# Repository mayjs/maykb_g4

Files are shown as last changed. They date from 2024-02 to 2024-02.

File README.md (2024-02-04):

# maykb G4

This is my fourth custom split keyboard, this time using an ANSI layout.

## Caveats / Known Issues

In its current form, the level shifter for the WS2812b LEDs does NOT work.
With most clones, you can just remove the Mosfet and the two resistors next to it and bridge the microcontroller LED data input directly to the LED data input.
Some LEDs might not properly recognize the 3.3V signal though, so you might see some glitches due to this.

Otherwise, the keyboard works without any issues.

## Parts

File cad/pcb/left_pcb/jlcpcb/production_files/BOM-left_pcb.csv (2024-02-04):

Comment | Designator | Footprint | LCSC
1k | R1,R2,R7 | R_0402_1005Metric | C11702
W25Q128JVS | U1 | SOIC-8_5.23x5.23mm_P1.27mm | C131025
100nF | C1,C10,C11,C12,C13,C14,C15,C18,C19,C20,C5,C6,C9 | C_0402_1005Metric | C1525
10uF | C7 | C_0402_1005Metric | C15525
22pF | C2,C3 | C_0402_1005Metric | C1555
USB_C_Receptacle_USB2.0 | J1 | USB_C_Receptacle_HRO_TYPE-C-31-M-12 | C165948
RP2040 | U3 | RP2040-QFN-56 | C2040
D | D1,D10,D11,D12,D13,D14,D15,D16,D17,D18,D19,D2,D20,D21,D22,D23,D24,D25,D26,D27,D28,D29,D3,D30,D31,D32,D4,D5,D6,D7,D8,D9 | D_SOD-323F | C2128
27R | R5,R6 | R_0603_1608Metric | C25190
5k1 | R3,R4 | R_0402_1005Metric | C25905
USBLC6-2SC6 | U2 | SOT-23-6 | C2827654
1uF | C16,C17,C4,C8 | C_0402_1005Metric | C52923
XC6206PxxxMR-Regulator_Linear | U4 | SOT-23 | C5446
ConnLeft | J3,J4 | PJ-342B | C668606
500mA | F1 | Fuse_1206_3216Metric | C70076
12MHz | Y1 | Crystal_SMD_3225-4Pin_3.2x2.5mm | C9002
10k | R8 | R_0603_1608Metric_Pad0.98x0.95mm_HandSolder
BSS138 | Q1 | SOT-23
10k | R9 | R_0603_1608Metric_Pad0.98x0.95mm_HandSolder

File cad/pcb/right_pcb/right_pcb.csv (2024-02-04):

Id | Designator | Footprint | Quantity | Designation | Supplier and ref
1 | LED3,LED1,LED2 | LED_WS2812B_PLCC4_5.0x5.0mm_P3.2mm | 3 | WS2812B
2 | SW49,SW48,SW55,SW70,SW75,SW54,SW39,SW57,SW74,SW76,SW47,SW62,SW66,SW33,SW50,SW35,SW45,SW73,SW59,SW42,SW34,SW63,SW58,SW61,SW41,SW43,SW51,SW64,SW38,SW60,SW44,SW36,SW40,SW53,SW52,SW46,SW72,SW71,SW56 | SW_Cherry_MX_1.00u_PCB | 39 | SW_Push_45deg
3 | SW69 | SW_Cherry_MX_2.25u_PCB | 1 | SW_Push_45deg
4 | SW67,SW37 | SW_Cherry_MX_2.00u_PCB | 2 | SW_Push_45deg
5 | SW68 | SW_Cherry_MX_1.50u_PCB | 1 | SW_Push_45deg
6 | SW65 | SW_Cherry_MX_1.75u_PCB | 1 | SW_Push_45deg
7 | C17,C8,C16,C4 | C_0402_1005Metric | 4 | 1uF
8 | C6,C1,C9,C14,C10,C13,C15,C18,C20,C19,C5,C12,C11 | C_0402_1005Metric | 13 | 100nF
9 | D46,D56,D53,D38,D43,D52,D36,D67,D39,D66,D47,D68,D75,D41,D48,D54,D35,D34,D65,D40,D50,D59,D37,D49,D58,D70,D42,D73,D51,D60,D44,D71,D55,D45,D72,D33,D61,D62,D63,D57,D64,D76,D74,D69 | D_SOD-323F | 44 | 1N4148
10 | U3 | RP2040-QFN-56 | 1 | RP2040
11 | R9,R8 | R_0603_1608Metric_Pad0.98x0.95mm_HandSolder | 2 | 10k
12 | C7 | C_0402_1005Metric | 1 | 10uF
13 | U1 | SOIC-8_5.23x5.23mm_P1.27mm | 1 | W25Q128JVS
14 | U2 | SOT-23-6 | 1 | USBLC6-2SC6
15 | C3,C2 | C_0402_1005Metric | 2 | 22pF
16 | R6,R5 | R_0603_1608Metric | 2 | 27R
17 | J4 | PJ-342B | 1 | ConnRight
18 | F1 | Fuse_1206_3216Metric | 1 | 500mA
19 | Y1 | Crystal_SMD_3225-4Pin_3.2x2.5mm | 1 | 12MHz
20 | Q1 | SOT-23 | 1 | BSS138
21 | R2,R1,R7 | R_0402_1005Metric | 3 | 1k
22 | R3,R4 | R_0402_1005Metric | 2 | 5k1
23 | J3 | PJ-342B | 1 | ConnLeft
24 | SW_RESET1 | SW_SPST_TL3342 | 1 | SW_Push
25 | J1 | USB_C_Receptacle_HRO_TYPE-C-31-M-12 | 1 | USB_C_Receptacle_USB2.0
26 | U4 | SOT-23 | 1 | XC6206PxxxMR-Regulator_Linear

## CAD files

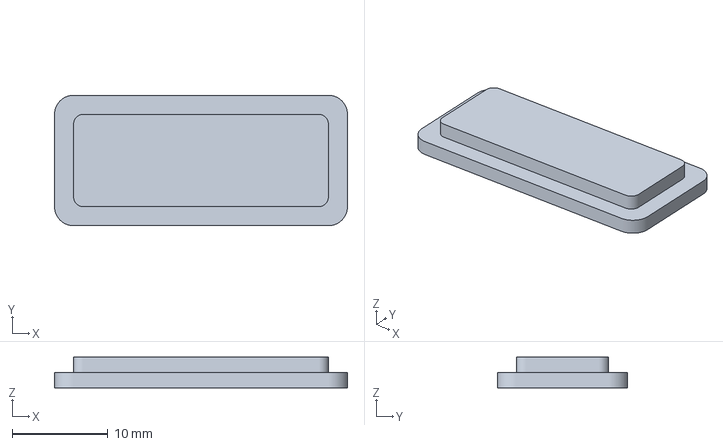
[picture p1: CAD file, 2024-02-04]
cad/case/led_cover.amf
30.7 x 13.7 x 3.20 mm

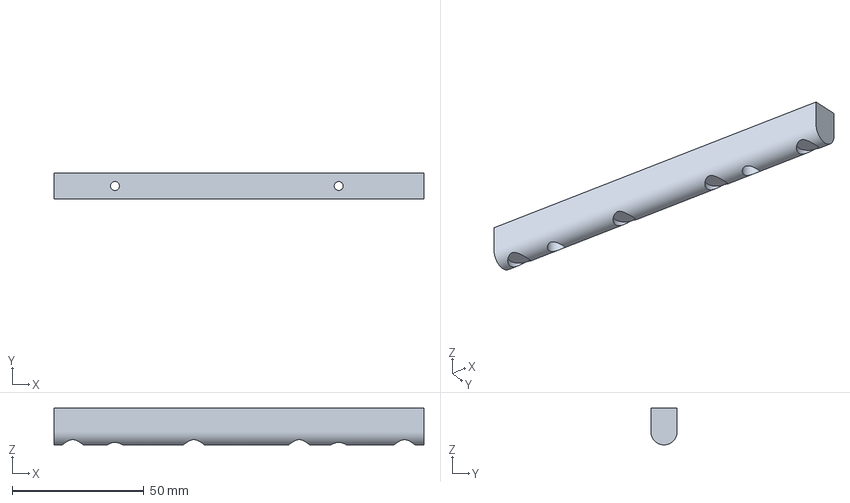
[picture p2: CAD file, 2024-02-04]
cad/case/left/left_bar.amf
140.5 x 10.0 x 14.0 mm

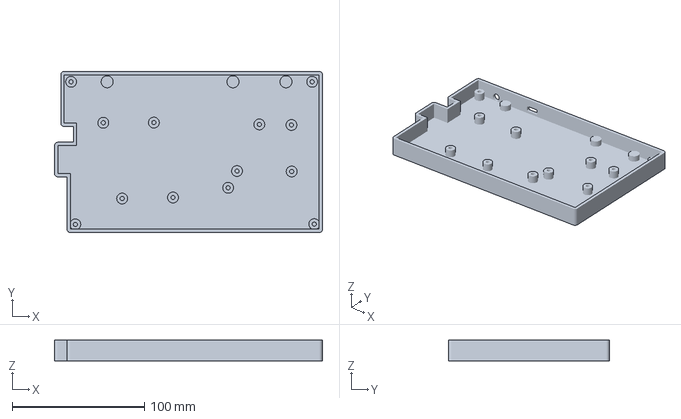
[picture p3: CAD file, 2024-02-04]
cad/case/right/right_case.amf
202.4 x 121.7 x 15.6 mm

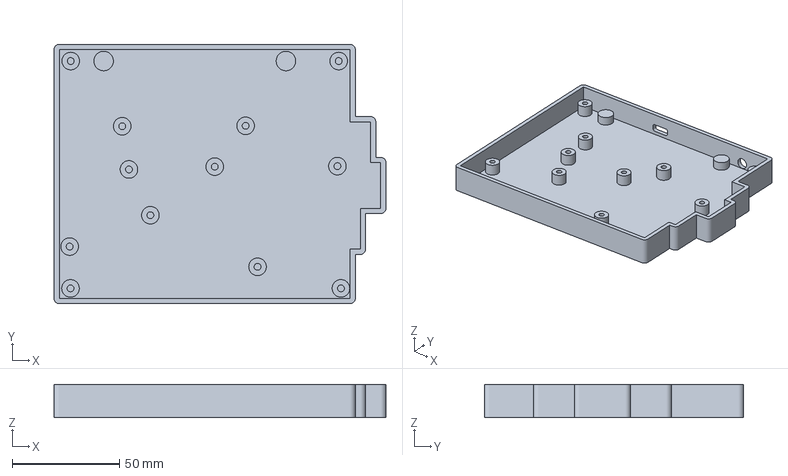
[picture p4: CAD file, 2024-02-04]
cad/case/left/left_case.amf
154.8 x 121.0 x 15.6 mm

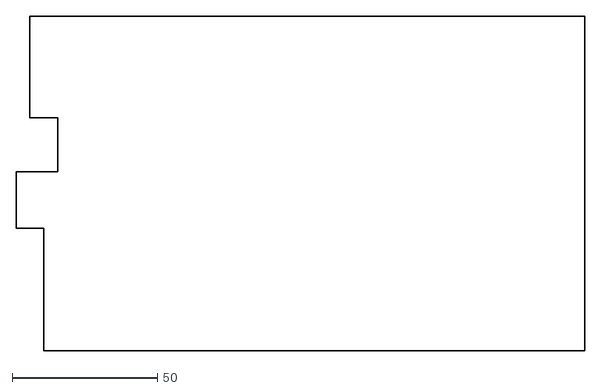
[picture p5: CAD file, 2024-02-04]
cad/case/right/right_pcb-Edge_Cuts.dxf
195.8 x 115.1

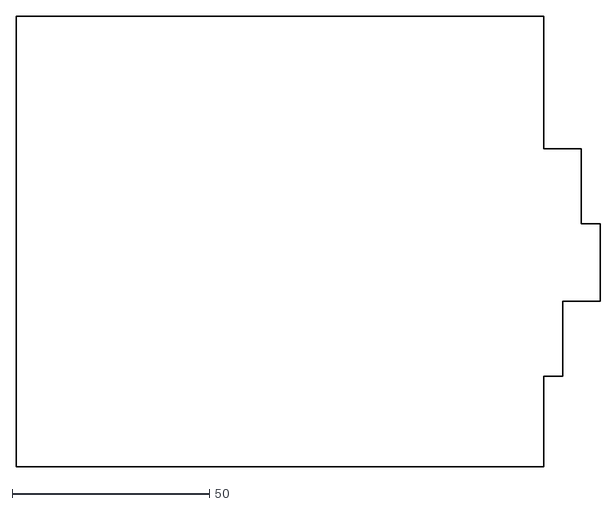
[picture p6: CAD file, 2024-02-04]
cad/case/left/left_pcb-Edge_Cuts.dxf
148.2 x 114.4

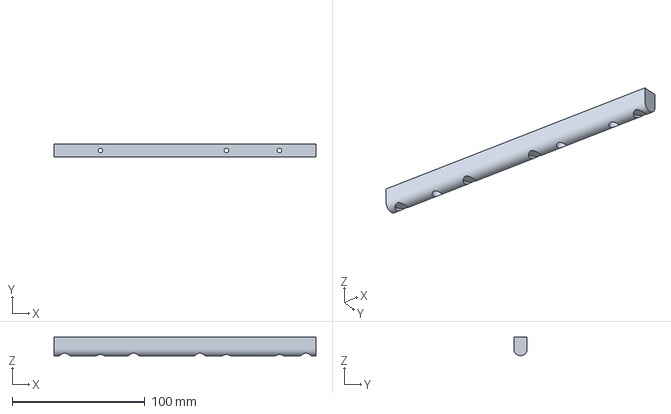
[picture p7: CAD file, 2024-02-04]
cad/case/right/right_bar.amf
197.7 x 10.0 x 14.0 mm

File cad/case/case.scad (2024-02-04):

// The case side to build
case_side = "left"; // [left, right]

// The part of the case to build
case_part = "case"; // [case, bar]

// The general amount of wiggle-room
play = .2;

// The amount of wiggle-room around the pcb and plate in the case
case_play = .8;

// The thickness of the outer case wall
wall_thickness = 2.5; // 0.1

// The drill diameter for the screw inserts
screw_insert_dia = 3.2;

// The length of the hole for the screw inserts
screw_insert_hole_length = 6.5;

// The total height of the plate-pcb sandwich
plate_pcb_height = 6.6;

// The diameter of the audio plug
audio_plug_dia = 6.2;

// The diameter of the mount holes for the angle bar
screw_insert_angle_bar_dia = 4.1;

// The length of the hole to mount the angle bar
screw_insert_angle_bar_hole_length = 5;

// The width of the angle bar
angle_bar_width = 10;

// The maximum allowed width for the bar (this should be larger than the keyboard / case)
max_bar_length = 300;

// the height of the angle bar (this must be at least angle_bar_width / 2)
angle_bar_height = 14;

// The diameter of the rubber bumpers
bumper_dia = 8;

$fn = 100;

is_left = case_side == "left" ? true : false;

edge_file = is_left ? "left/left_pcb-Edge_Cuts.dxf" : "right/right_pcb-Edge_Cuts.dxf";

use <left/coordinates.scad>
use <right/coordinates.scad>

mount_positions = is_left ? kb_mount_centers_left() : kb_mount_centers_right();
jack_positions = is_left ? [max(audio_jack_x_left())] : [min(audio_jack_x_right())];
usb_c_position = is_left ? usb_c_x_left() : usb_c_x_right();
angle_bar_mount_positions = is_left ? [50, 135] : [75, 170, 210];
bumper_mount_positions = is_left ? [34, 80, 120, 160] : [48, 100, 150, 230];

angle_bar_y_position = -min([for(pos = mount_positions) pos.y]);

usb_c_jack_bounds = [10, 4];
 
use <mayscadlib/2d/shapes.scad>
use <mayscadlib/3d/screws.scad>
use <mayscadlib/positioning.scad>

module outline() {
    offset(delta=case_play)
    import(edge_file);
}

module wall_2d() {
  difference() {
    offset(r=wall_thickness)
    outline();
    outline();
  }
}

module bare_case() {
    linear_extrude(wall_thickness) {
        wall_2d();
        outline();
    }

    linear_extrude(wall_thickness + screw_insert_hole_length + plate_pcb_height)
    wall_2d();
}

module mounting_post() {
    linear_extrude(screw_insert_hole_length)
    difference() {
        circle(r=screw_insert_dia/2 + wall_thickness);
        circle(r=screw_insert_dia/2);
    }
}

module mounts() {
    for(pos = mount_positions) {
        translate([pos.x, -pos.y, wall_thickness - .0001]) {
            mounting_post();        
        }
    }
}

module connector_cutouts() {
    // usb-c
    bounds_with_play = usb_c_jack_bounds + [2*play, 2*play];
    translate([usb_c_position.x, 0, wall_thickness + screw_insert_hole_length - bounds_with_play.y/2])
    rotate([90,0,0])
    linear_extrude(100)
    rounded_square(bounds_with_play, corner_rad=1, center=true);

    // audio jack
    for(pos = jack_positions) {
        rad = audio_plug_dia/2 + play/2;
        translate([pos, 0, wall_thickness + screw_insert_hole_length - rad])
        rotate([90,0,0])
        cylinder(r=rad, 100);
    }
}

module case_with_angle_bar_mounts() {
    difference() {
        union() {
            bare_case();
            for(mx = angle_bar_mount_positions) {
                translate([mx, angle_bar_y_position, wall_thickness - .0001])
                cylinder(r=screw_insert_angle_bar_dia/2 + wall_thickness, h=screw_insert_angle_bar_hole_length);
            }
        }
        for(mx = angle_bar_mount_positions) {
            translate([mx, angle_bar_y_position, -.0001])
            cylinder(r=screw_insert_angle_bar_dia/2, h=screw_insert_angle_bar_hole_length);
        }
    }
}

module full_case() {
    difference() {
        case_with_angle_bar_mounts();
        connector_cutouts();
    }
    mounts();
}

module bar() {
    screw = m3_din912_cylinder_head(angle_bar_height * 2);

    bumper_plateau_inv_height = sqrt(pow(angle_bar_width/2, 2) - pow(bumper_dia/2, 2));
    bumper_plateau_height = angle_bar_width/2 - bumper_plateau_inv_height;

    difference() {
        intersection() {
            translate([0, angle_bar_y_position, angle_bar_width/2])
            rotate([90,0,90])
            linear_extrude(max_bar_length) {
                difference() {
                    circle(r=angle_bar_width/2); 
                    translate([-angle_bar_width,0])
                    square([angle_bar_width *2, angle_bar_width]);
                }

                translate([-angle_bar_width / 2, 0])
                square([angle_bar_width, angle_bar_height - angle_bar_width / 2]);
            }

            linear_extrude(max_bar_length + 1) {
                outline();
                wall_2d();
            }
        }

        for(mx = angle_bar_mount_positions) {
            translate([mx, angle_bar_y_position, angle_bar_height - screw_head_h(screw) - wall_thickness])
            mirror([0,0,1]) 
            make_screw(screw, head_clearance=angle_bar_width);

        }

        translate([0, angle_bar_y_position, -.0001])
        place([for (bx=bumper_mount_positions) [bx, 0]])
        cylinder(r=bumper_dia/2, h=bumper_plateau_height);
    }
}

if(case_part == "case") {
    full_case();
} else if (case_part == "bar") {
    bar(); 
}

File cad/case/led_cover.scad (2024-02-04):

use <mayscadlib/2d/shapes.scad>
use <mayscadlib/positioning.scad>

$fn = 100;

hole_dims = [26.67, 9.652];
lip = 2;
thickness = 1.6;

linear_extrude(thickness)
rounded_square(hole_dims + [lip*2, lip*2], corner_rad=2, center=true);

lift(thickness)
linear_extrude(thickness)
rounded_square(hole_dims, center=true);

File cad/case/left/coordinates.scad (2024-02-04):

function kb_footprint_centers_left() = [
    [90.1369,91.54],
    [113.9494,148.69],
    [166.3369,91.54],
    [147.2869,91.54],
    [54.4925,129.64],
    [71.0869,91.54],
    [61.5619,72.49],
    [137.7619,72.49],
    [161.5744,129.64],
    [47.2749,91.54],
    [92.5179,148.69],
    [109.1869,91.54],
    [42.5119,72.49],
    [80.6119,72.49],
    [118.7119,72.49],
    [94.8994,110.59],
    [68.7054,148.69],
    [123.4744,129.64],
    [113.9494,110.59],
    [156.8119,72.49],
    [85.3744,129.64],
    [99.6619,72.49],
    [128.2369,91.54],
    [144.98,148.69],
    [152.0494,110.59],
    [132.9994,110.59],
    [75.8494,110.59],
    [142.5244,129.64],
    [171.0994,110.59],
    [104.4244,129.64],
    [44.8929,148.69],
    [49.6559,110.59],
];

function kb_mount_centers_left() = [
    [160.65,163.6556],
    [58.65,88.05],
    [61.8,108.2],
    [121.75,153.6],
    [71.8,129.55],
    [159.5996,57.6556],
    [34.15,144.1556],
    [159.0,106.6556],
    [34.6496,57.6556],
    [34.5496,163.6556],
    [116.2,87.85],
    [101.8,106.9],
];

function audio_jack_x_left() = [
    48.0,
    146.1,
];

function usb_c_x_left() = [
    85.845968,
];

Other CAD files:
cad/case/right/coordinates.scad

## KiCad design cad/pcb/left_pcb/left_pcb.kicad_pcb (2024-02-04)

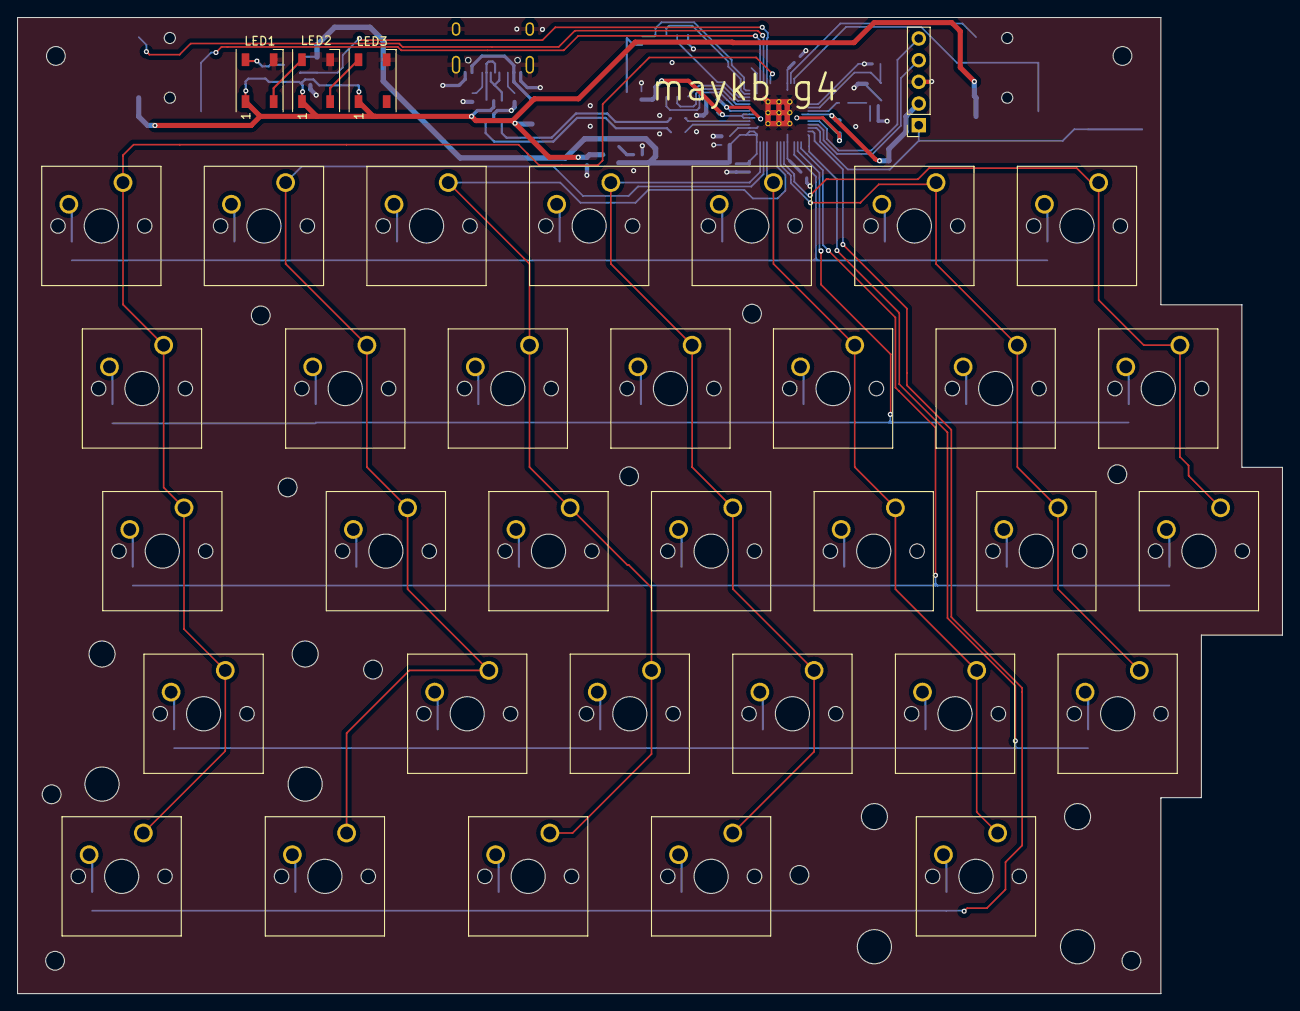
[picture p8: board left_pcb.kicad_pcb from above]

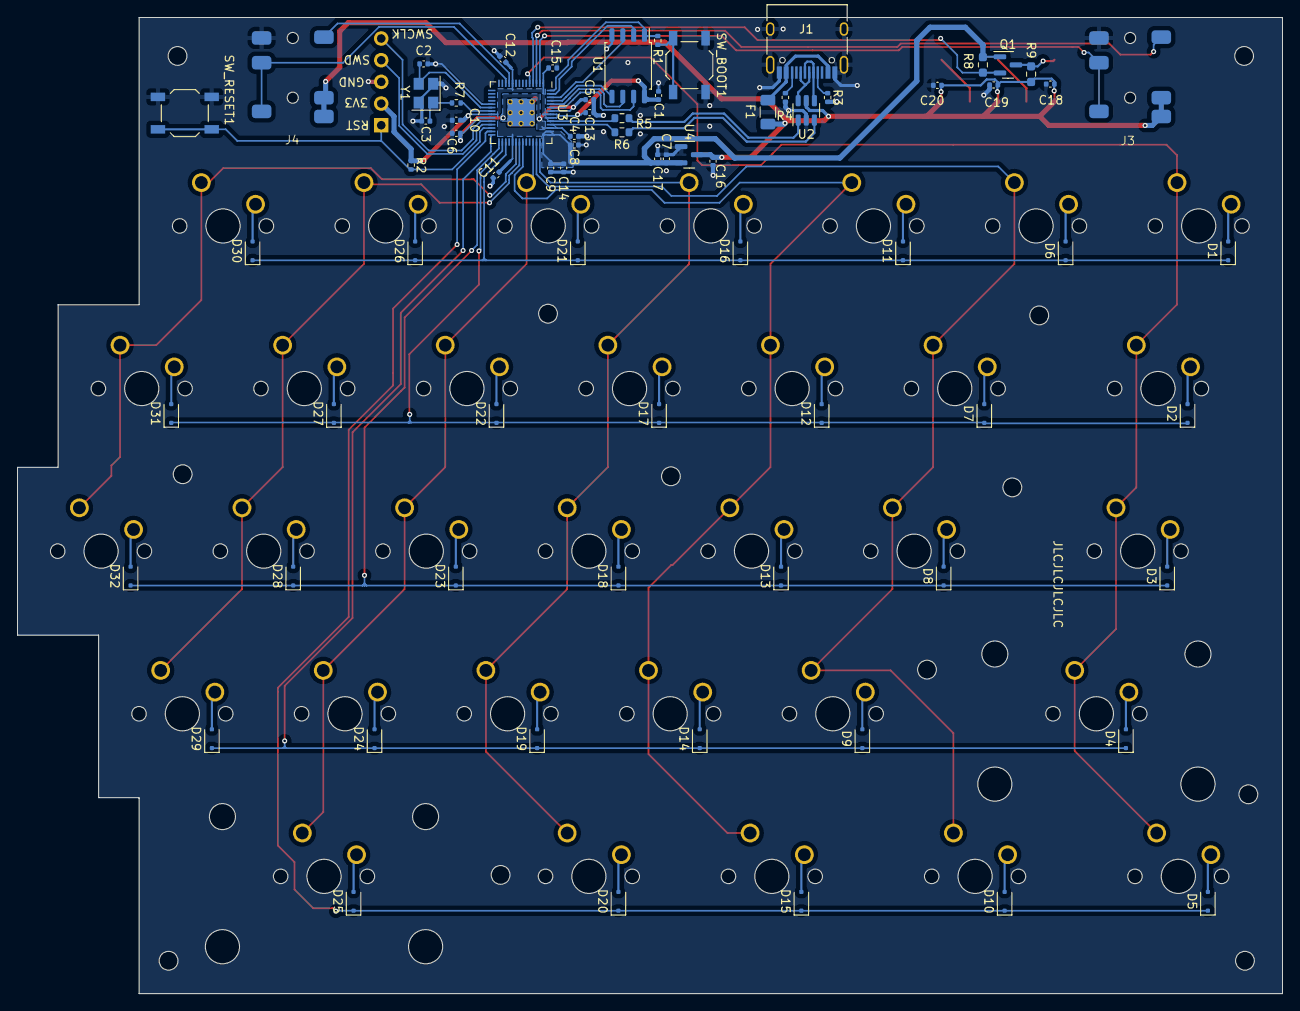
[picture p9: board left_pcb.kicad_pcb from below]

Board: 2 copper layers, 148.2 x 114.4 mm, 109 parts (73 on the bottom side), 78 nets.

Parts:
C1, C5, C6, C9, C10, C11, C12, C13, C14, C15, C18, C19, C20: 100nF; C_0402_1005Metric
C2, C3: 22pF; C_0402_1005Metric
C4, C8, C16, C17: 1uF; C_0402_1005Metric
C7: 10uF; C_0402_1005Metric
D1, D2, D3, D4, D5, D6, D7, D8, D9, D10, D11, D12, D13, D14, D15, D16, D17, D18, D19, D20, D21, D22, D23, D24, D25, D26, D27, D28, D29, D30, D31, D32: D; D_SOD-323F
F1: 500mA; Fuse_1206_3216Metric
J1: USB_C_Receptacle_USB2.0; USB_C_Receptacle_HRO_TYPE-C-31-M-12
J2: SWD; PinSocket_1x05_P2.54mm_Vertical
J3: ConnLeft; PJ-342B
J4: ConnRight; PJ-342B
LED1, LED2, LED3: WS2812B; LED_WS2812B_PLCC4_5.0x5.0mm_P3.2mm
Q1: BSS138; SOT-23
R1, R2, R7: 1k; R_0402_1005Metric
R3, R4: 5k1; R_0402_1005Metric
R5, R6: 27R; R_0603_1608Metric
R8, R9: 10k; R_0603_1608Metric_Pad0.98x0.95mm_HandSolder
SW1, SW6, SW7, SW8, SW9, SW11, SW12, SW13, SW14, SW16, SW17, SW18, SW19, SW20, SW21, SW22, SW23, SW24, SW26, SW27, SW28, SW29, SW30, SW31, SW32: SW_Push_45deg; SW_Cherry_MX_1.00u_PCB
SW2: SW_Push_45deg; SW_Cherry_MX_1.50u_PCB
SW3: SW_Push_45deg; SW_Cherry_MX_1.75u_PCB
SW4, SW25: SW_Push_45deg; SW_Cherry_MX_2.25u_PCB
SW5, SW10, SW15: SW_Push_45deg; SW_Cherry_MX_1.25u_PCB
SW_BOOT1: SW_Push; SW_SPST_TL3342
SW_RESET1: SW_Push; SW_SPST_TL3342
U1: W25Q128JVS; SOIC-8_5.23x5.23mm_P1.27mm
U2: USBLC6-2SC6; SOT-23-6
U3: RP2040; RP2040-QFN-56
U4: XC6206PxxxMR-Regulator_Linear; SOT-23
Y1: 12MHz; Crystal_SMD_3225-4Pin_3.2x2.5mm

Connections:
+1V1: C4.1, C5.1, C6.1, U3.23 (DVDD), U3.45 (VREG_VOUT), U3.50 (DVDD)
+3.3V: C1.1, C7.1, C8.1, C9.1, C10.1, C11.1, C12.1, C13.1, C14.1, C15.1, C17.2, J2.2, Q1.1 (G), R2.1, R8.1, U1.8 (VCC), U3.1 (IOVDD), U3.10 (IOVDD), U3.22 (IOVDD), U3.33 (IOVDD), U3.42 (IOVDD), U3.43 (ADC_AVDD), U3.44 (VREG_VIN), U3.48 (USB_VDD), U3.49 (IOVDD), U4.2 (VO)
+5V: C16.2, C18.1, C19.1, C20.1, F1.2, J3.T, J4.T, LED1.1 (VDD), LED2.1 (VDD), LED3.1 (VDD), R9.1, U2.5 (VBUS), U4.3 (VI)
/COL1: SW1.1, SW2.1, SW3.1, SW4.1, SW5.1, U3.5 (GPIO3)
/COL2: SW6.1, SW7.1, SW8.1, SW9.1, SW10.1, U3.40 (GPIO28/ADC2)
/COL3: SW11.1, SW12.1, SW13.1, SW14.1, SW15.1, U3.36 (GPIO24)
/COL4: SW16.1, SW17.1, SW18.1, SW19.1, SW20.1, U3.41 (GPIO29/ADC3)
/COL5: SW21.1, SW22.1, SW23.1, SW24.1, SW25.1, U3.39 (GPIO27/ADC1)
/COL6: SW26.1, SW27.1, SW28.1, SW29.1, U3.35 (GPIO23)
/COL7: SW30.1, SW31.1, SW32.1, U3.34 (GPIO22)
/LED_DATA: Q1.2 (S), R8.2, U3.4 (GPIO2)
/LEFT_RX: J3.R2, U3.3 (GPIO1)
/LEFT_TX: J3.R1, U3.2 (GPIO0)
/RIGHT_RX: J4.R1, U3.12 (GPIO9)
/RIGHT_TX: J4.R2, U3.11 (GPIO8)
/ROW1: D1.1 (K), D6.1 (K), D11.1 (K), D16.1 (K), D21.1 (K), D26.1 (K), D30.1 (K), U3.31 (GPIO20)
/ROW2: D2.1 (K), D7.1 (K), D12.1 (K), D17.1 (K), D22.1 (K), D27.1 (K), D31.1 (K), U3.30 (GPIO19)
/ROW3: D3.1 (K), D8.1 (K), D13.1 (K), D18.1 (K), D23.1 (K), D28.1 (K), D32.1 (K), U3.29 (GPIO18)
/ROW4: D4.1 (K), D9.1 (K), D14.1 (K), D19.1 (K), D24.1 (K), D29.1 (K), U3.28 (GPIO17)
/ROW5: D5.1 (K), D10.1 (K), D15.1 (K), D20.1 (K), D25.1 (K), U3.27 (GPIO16)
/pi-pico/CC1: J1.A5 (CC1), R3.1
/pi-pico/CC2: J1.B5 (CC2), R4.1
/pi-pico/D_+: R5.2, U3.47 (D+)
/pi-pico/D_-: R6.2, U3.46 (D-)
/pi-pico/XTAL_O: C3.2, R7.1, Y1.1
/pi-pico/~USB_BOOT: R1.1, SW_BOOT1.2
CS: R1.2, U1.1 (~CS), U3.56 (QSPI_SS_N)
D_N: R6.1, U2.3 (I/O2)
D_P: R5.1, U2.1 (I/O1)
D_USB_N: J1.A7 (D-), J1.B7 (D-), U2.4 (I/O2)
D_USB_P: J1.A6 (D+), J1.B6 (D+), U2.6 (I/O1)
GND: C1.2, C2.1, C3.1, C4.2, C5.2, C6.2, C7.2, C8.2, C9.2, C10.2, C11.2, C12.2, C13.2, C14.2, C15.2, C16.1, C17.1, C18.2, C19.2, C20.2, J1.A1 (GND), J1.A12 (GND), J1.B1 (GND), J1.B12 (GND), J1.S1 (SHIELD), J2.3, J3.S, J4.S, LED1.3 (VSS), LED2.3 (VSS), LED3.3 (VSS), R3.2, R4.2, SW_BOOT1.1, SW_RESET1.1, U1.4 (GND), U2.2 (GND), U3.19 (TESTEN), U3.57 (GND), U4.1 (GND), Y1.2, Y1.4
unnamed: D1.2 (A), SW1.2
unnamed: D2.2 (A), SW2.2
unnamed: D3.2 (A), SW3.2
unnamed: D4.2 (A), SW4.2
unnamed: D5.2 (A), SW5.2
unnamed: D6.2 (A), SW6.2
unnamed: D7.2 (A), SW7.2
unnamed: D8.2 (A), SW8.2
unnamed: D9.2 (A), SW9.2
unnamed: D10.2 (A), SW10.2
unnamed: D11.2 (A), SW11.2
unnamed: D12.2 (A), SW12.2
unnamed: D13.2 (A), SW13.2
unnamed: D14.2 (A), SW14.2
unnamed: D15.2 (A), SW15.2
unnamed: D16.2 (A), SW16.2
unnamed: D17.2 (A), SW17.2
unnamed: D18.2 (A), SW18.2
unnamed: D19.2 (A), SW19.2
unnamed: D20.2 (A), SW20.2
unnamed: D21.2 (A), SW21.2
unnamed: D22.2 (A), SW22.2
unnamed: D23.2 (A), SW23.2
unnamed: D24.2 (A), SW24.2
unnamed: D25.2 (A), SW25.2
unnamed: D26.2 (A), SW26.2
unnamed: D27.2 (A), SW27.2
unnamed: D28.2 (A), SW28.2
unnamed: D29.2 (A), SW29.2
unnamed: D30.2 (A), SW30.2
unnamed: D31.2 (A), SW31.2
unnamed: D32.2 (A), SW32.2
unnamed: LED1.4 (DIN), Q1.3 (D), R9.2
unnamed: LED1.2 (DOUT), LED2.4 (DIN)
unnamed: LED2.2 (DOUT), LED3.4 (DIN)
QSPI_CLK: U1.6 (CLK), U3.52 (QSPI_SCLK)
SD0: U1.5 (DI(IO0)), U3.53 (QSPI_SD0)
SD1: U1.2 (DO(IO1)), U3.55 (QSPI_SD1)
SD2: U1.3 (IO2), U3.54 (QSPI_SD2)
SD3: U1.7 (IO3), U3.51 (QSPI_SD3)
SWCLK: J2.5, U3.24 (SWCLK)
SWD: J2.4, U3.25 (SWDIO)
VBUS: F1.1, J1.A4 (VBUS), J1.A9 (VBUS), J1.B4 (VBUS), J1.B9 (VBUS)
XTAL_IN: C2.2, U3.20 (XTAL_IN), Y1.3
XTAL_OUT: R7.2, U3.21 (XTAL_OUT)
~RESET: J2.1, R2.2, SW_RESET1.2, U3.26 (~RUN)
